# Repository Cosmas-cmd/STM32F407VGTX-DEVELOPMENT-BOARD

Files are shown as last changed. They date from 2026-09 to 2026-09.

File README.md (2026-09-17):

# Quick Preview
<p style="text-align:left;font-size:16px;color:white;">A custom STM32F407VGTx development board designed in KiCad 9.0, featuring the STM32F407 (LQFP100, Cortex-M4F @ 168 MHz) with an external crystal, USB Type-C power input, onboard microSD card slot, a user-programmable RGB LED, a "PWR ON" status LED, dedicated Wake-Up and Reset buttons, a BOOT0 force-boot jumper (JP1) for entering the system bootloader, an SWD/JTAG debug header for programming and debugging, and two 2×25 GPIO headers breaking out nearly the full MCU pinout along with 3V3/5V/GND rails for easy prototyping and shield/breadboard use.</p>
<p style="text-align:left;font-size:16px;color:white;text-decoration:underline">AN STM32F407VGTX BASED DEVELOPMENT BOARD</p>

<p style="margin-left:50px">
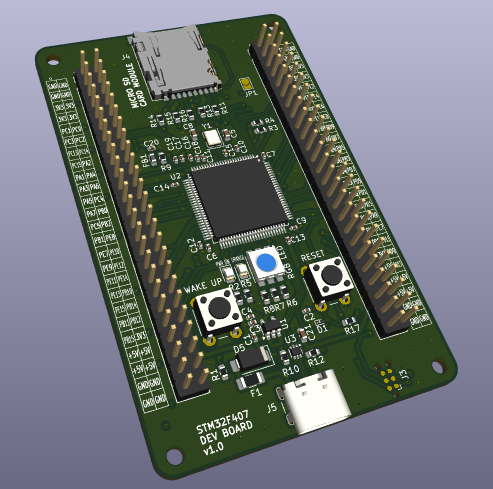
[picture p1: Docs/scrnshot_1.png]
  
</p>

<p style="text-align:left;font-size:16px;color:white">Frontside_1 view of the development board </p>

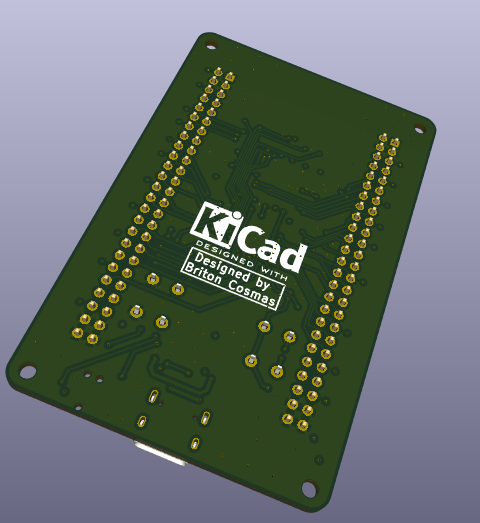
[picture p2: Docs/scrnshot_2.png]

</p>
<p style="text-align:left;font-size:16px;color:white">Bottomside view of the development board</p>

<p align="center">
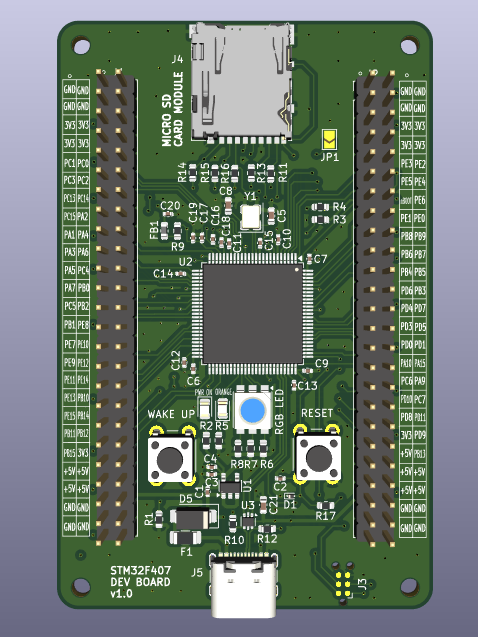
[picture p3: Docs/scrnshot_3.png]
  
</p>

<p style="text-align:left;font-size:16px;color:white">Frontside_2 view of the development board</p>

<p align="center">
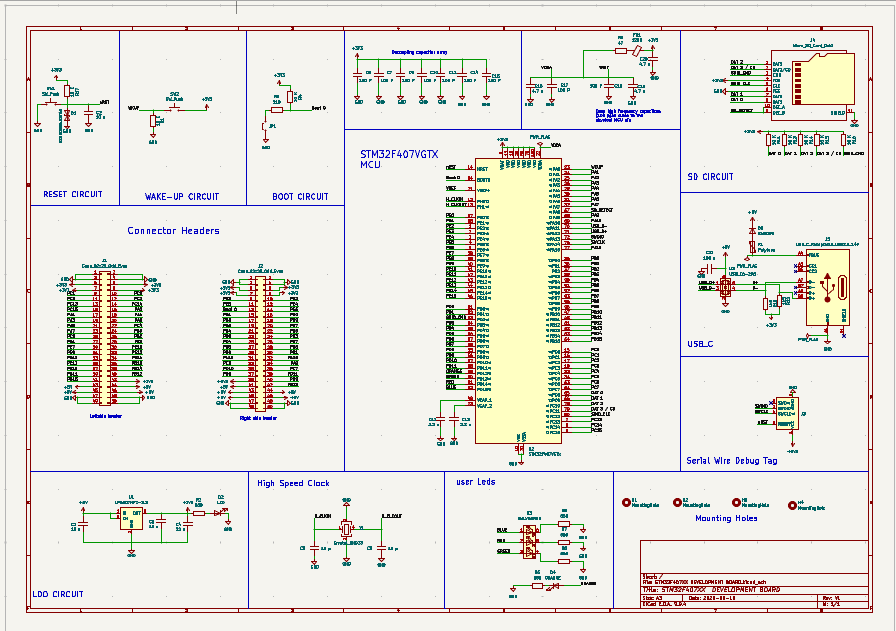
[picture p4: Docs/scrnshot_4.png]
  
</p>

<p style="text-align:left;font-size:16px;color:white">Schematic view of the development board circuit</p>
<p style="text-align:left;">**The schematic has also been provided as a pdf in this repository for clear viewing</p>

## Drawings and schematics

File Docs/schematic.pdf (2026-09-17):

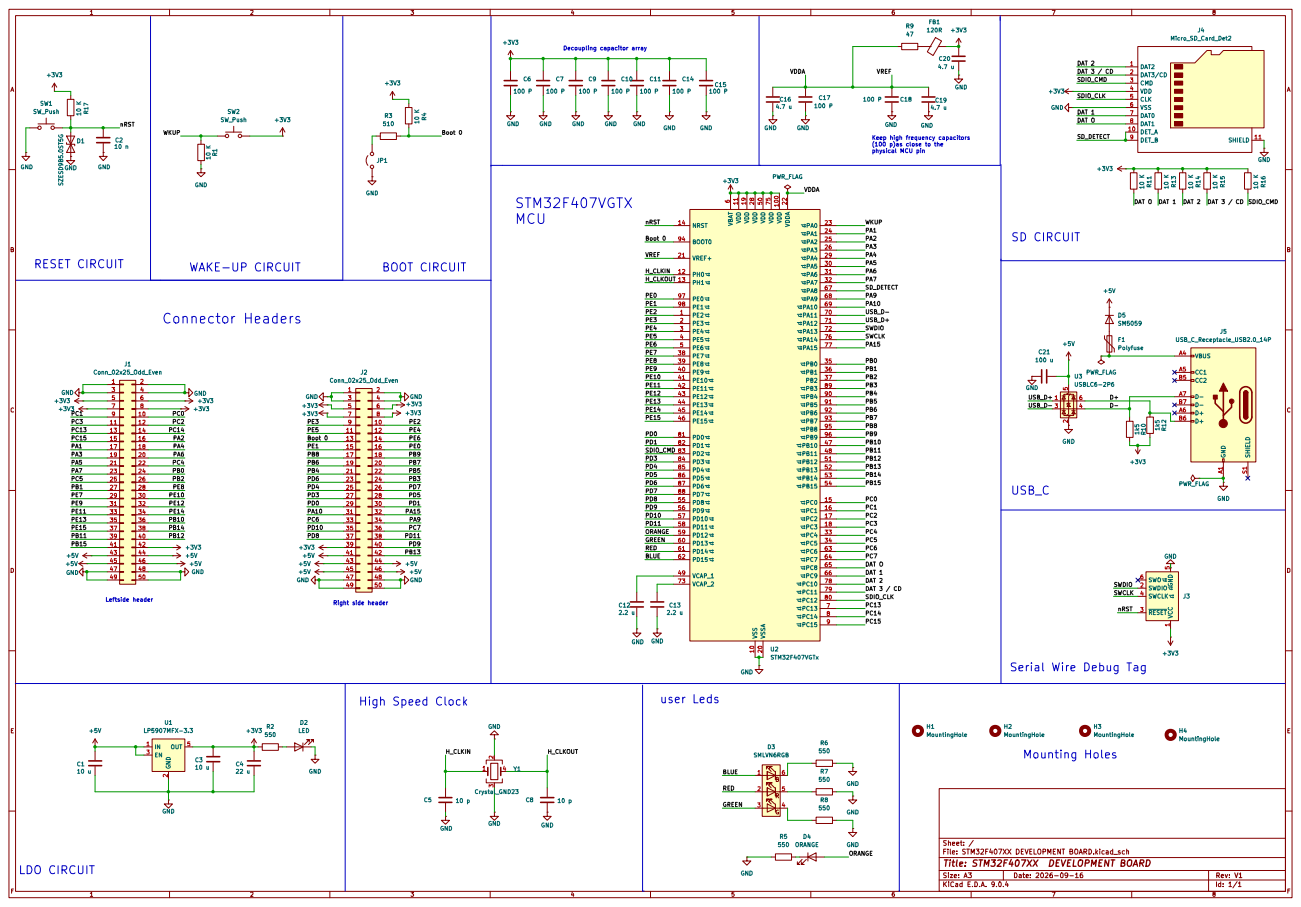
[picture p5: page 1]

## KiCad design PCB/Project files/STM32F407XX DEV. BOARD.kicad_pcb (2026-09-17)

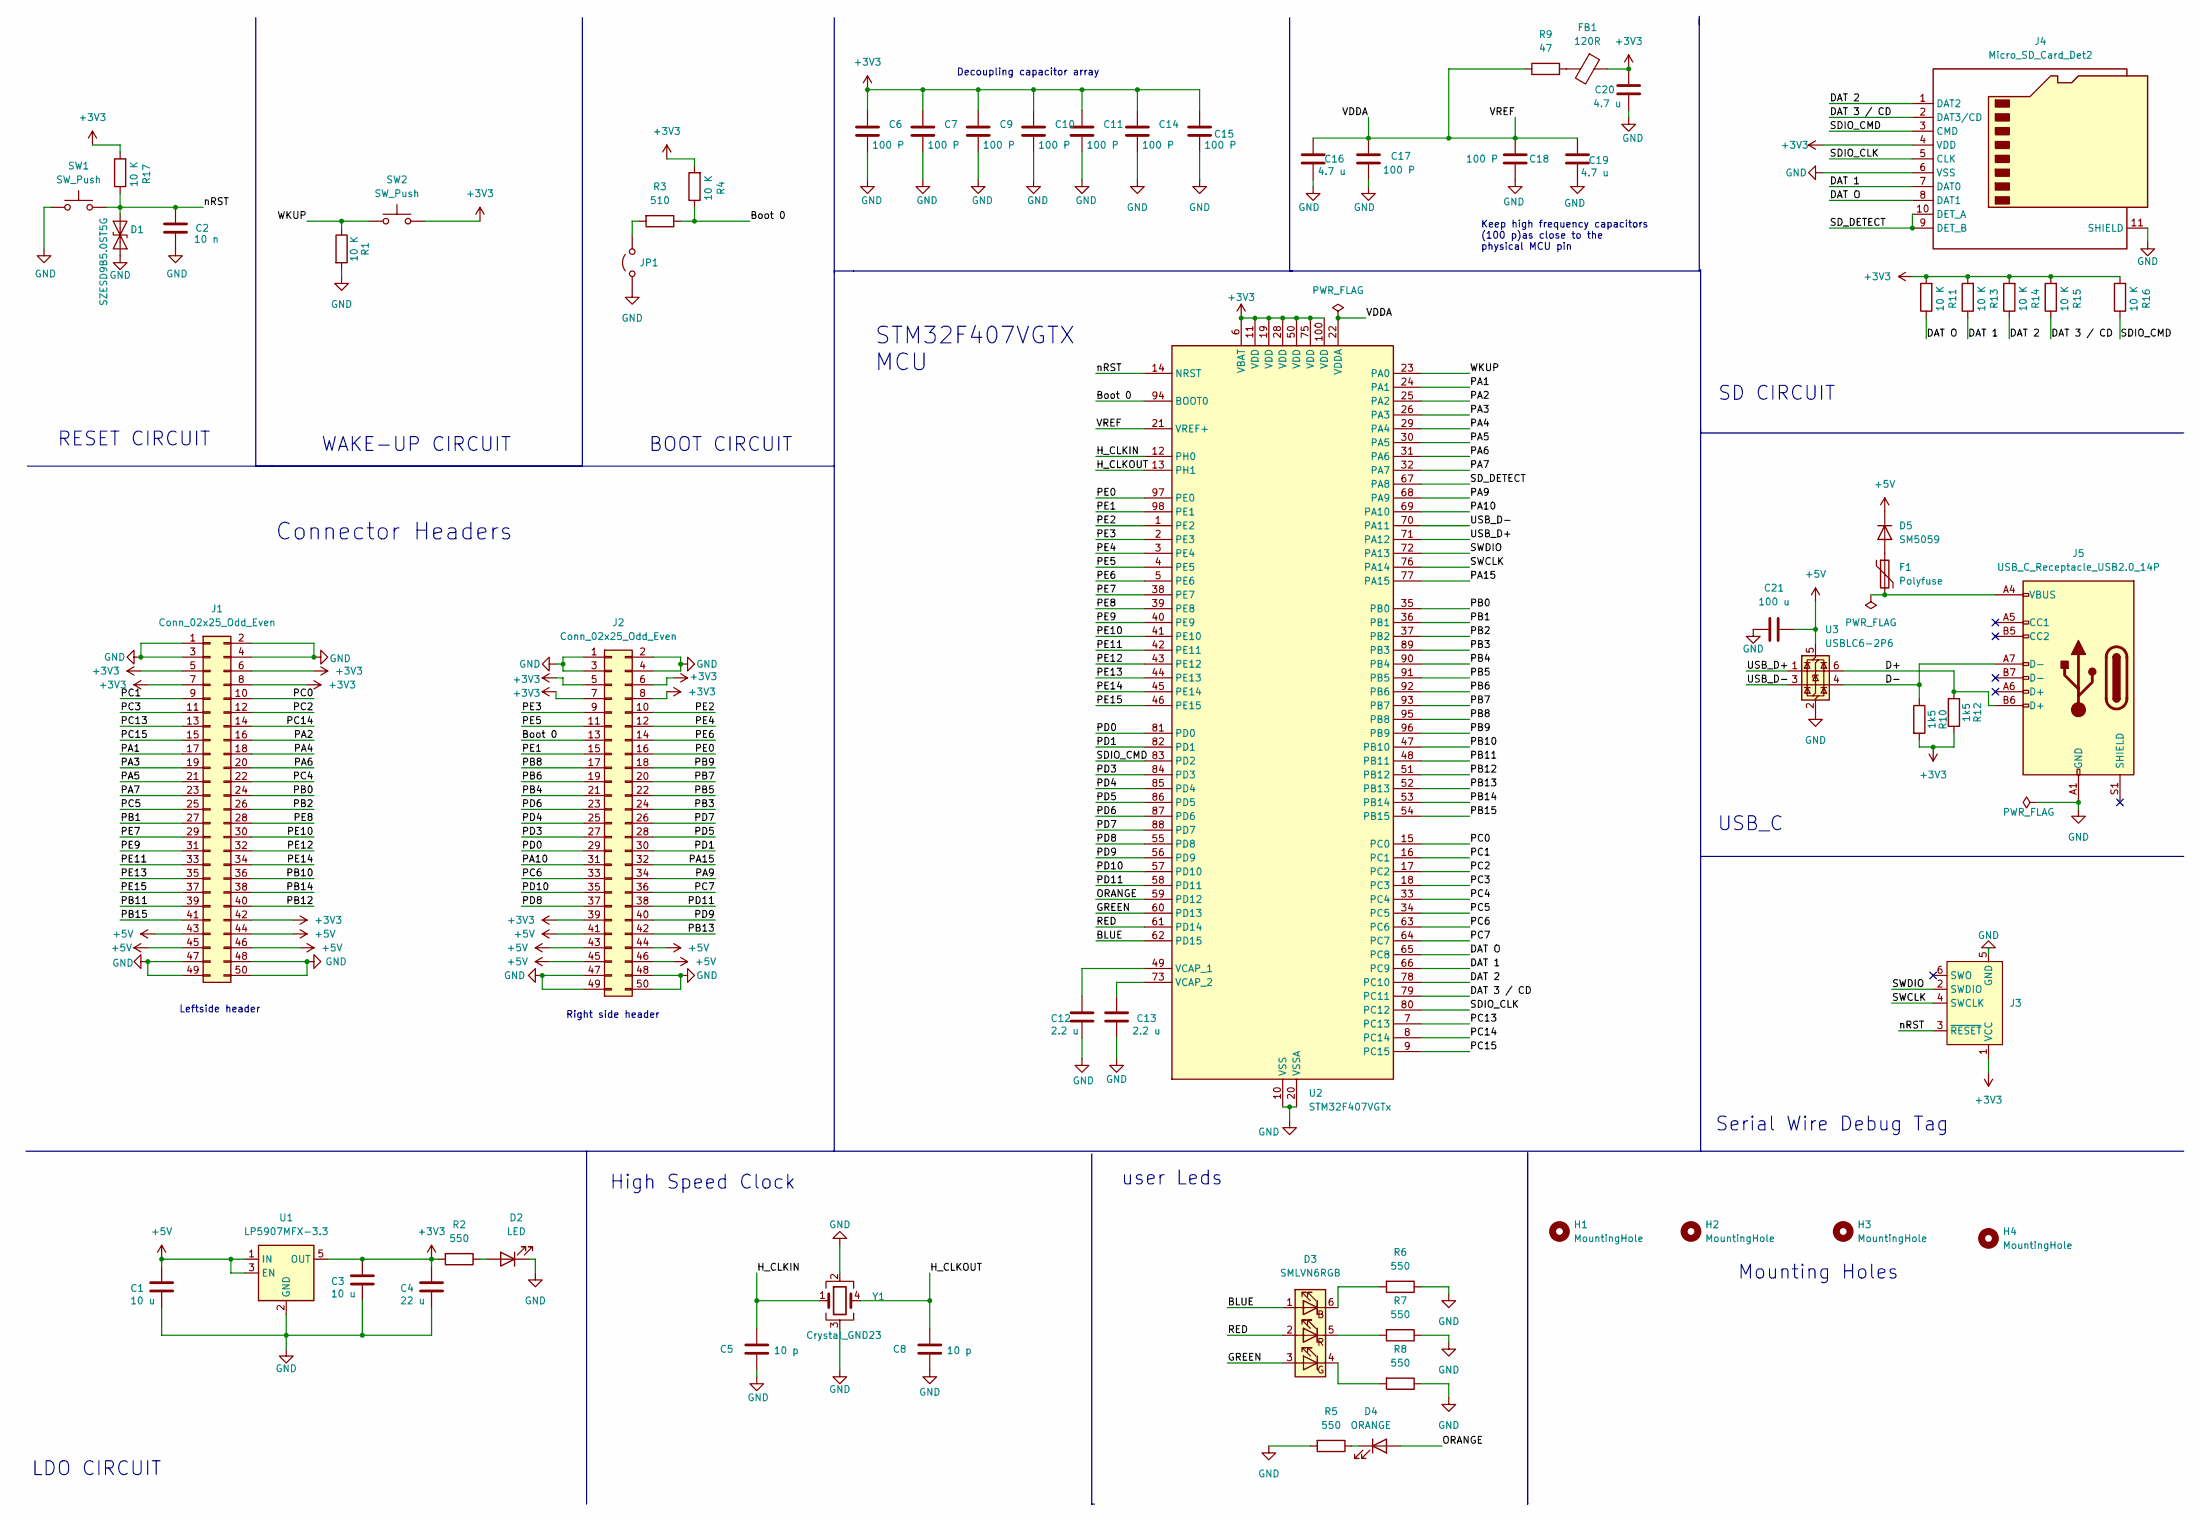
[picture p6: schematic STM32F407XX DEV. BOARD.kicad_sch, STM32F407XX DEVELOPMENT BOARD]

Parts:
C1, C3: 10 u; C_0402_1005Metric
C2: 10 n; C_0402_1005Metric
C4: 22 u; C_0402_1005Metric
C5, C8: 10 p; C_0603_1608Metric
C6, C7, C9, C10, C11, C14, C15, C17, C18: 100 P; C_0402_1005Metric
C12, C13: 2.2 u; C_0402_1005Metric
C16, C19, C20: 4.7 u; C_0402_1005Metric
C21: 100 u; C_0603_1608Metric
D1: SZESD9B5.0ST5G; D_SOD-923
D2: LED; LED_0805_2012Metric
D3: SMLVN6RGB; LED_RGB_5050-6
D4: ORANGE; LED_0805_2012Metric
D5: SM5059; D_SMA
F1: Polyfuse; Fuse_1206_3216Metric_Pad1.42x1.75mm_HandSolder
FB1: 120R; L_0603_1608Metric
H1, H2, H3, H4: MountingHole; MountingHole_2.5mm
J1, J2: Conn_02x25_Odd_Even; PinHeader_2x25_P2.54mm_Vertical
J3: Conn_ARM_SWD_TagConnect_TC2030-NL; Tag-Connect_TC2030-IDC-NL_2x03_P1.27mm_Vertical
J4: Micro_SD_Card_Det2; microSD_HC_Hirose_DM3AT-SF-PEJM5
J5: USB_C_Receptacle_USB2.0_14P; USB_C_Receptacle_GCT_USB4105-xx-A_16P_TopMnt_Horizontal
JP1: Jumper_2_Open; SolderJumper-2_P1.3mm_Open_TrianglePad1.0x1.5mm
R1, R4, R11, R13, R14, R15, R16, R17: 10 K; R_0603_1608Metric
R2, R5, R6, R7, R8: 550; R_0603_1608Metric
R3: 510; R_0603_1608Metric
R9: 47; R_0603_1608Metric
R10, R12: 1k5; R_0603_1608Metric
SW1, SW2: SW_Push; SW_PUSH_6mm
U1: LP5907MFX-3.3; SOT-23-5
U2: STM32F407VGTx; LQFP-100_14x14mm_P0.5mm
U3: USBLC6-2P6; SOT-666
Y1: Crystal_GND23; Crystal_SMD_3225-4Pin_3.2x2.5mm

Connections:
+3V3: C3.1, C4.1, C6.1, C7.1, C9.1, C10.1, C11.1, C14.1, C15.1, C20.1, FB1.1, J1.5, J1.6, J1.7, J1.8, J1.42, J2.5, J2.6, J2.7, J2.8, J2.39, J3.1 (VCC), J4.4 (VDD), R2.2, R4.2, R10.2, R11.2, R12.2, R13.2, R14.2, R15.2, R16.2, R17.2, SW2.2, U1.5 (OUT), U2.6 (VBAT), U2.11 (VDD), U2.19 (VDD), U2.28 (VDD), U2.50 (VDD), U2.75 (VDD), U2.100 (VDD)
+5V: C1.1, C21.2, D5.1 (K), J1.43, J1.44, J1.45, J1.46, J2.41, J2.43, J2.44, J2.45, J2.46, U1.1 (IN), U1.3 (EN), U3.5 (VBUS)
/BLUE: D3.1 (BA), U2.62 (PD15); also elsewhere on the board
/Boot 0: J2.13, R3.1, R4.1, U2.94 (BOOT0)
/D+: J5.B6 (D+), R12.1, U3.6 (I/O1)
/D-: J5.A7 (D-), R10.1, U3.4 (I/O2)
/DAT 1: J4.7 (DAT0), R13.1, U2.66 (PC9)
/DAT 2: J4.1 (DAT2), R14.1, U2.78 (PC10)
/DAT 3 / CD: J4.2 (DAT3/CD), R15.1, U2.79 (PC11)
/DAT O: J4.8 (DAT1), R11.1, U2.65 (PC8)
/GREEN: D3.3 (GA), U2.60 (PD13); also elsewhere on the board
/H_CLKIN: C5.1, U2.12 (PH0), Y1.1
/H_CLKOUT: C8.1, U2.13 (PH1), Y1.4
/ORANGE: D4.2 (A), U2.59 (PD12)
/PA1: J1.17, U2.24 (PA1)
/PA2: J1.16, U2.25 (PA2)
/PA3: J1.19, U2.26 (PA3)
/PA4: J1.18, U2.29 (PA4)
/PA5: J1.21, U2.30 (PA5)
/PA6: J1.20, U2.31 (PA6)
/PA7: J1.23, U2.32 (PA7)
/PA9: J2.34, U2.68 (PA9)
/PA10: J2.31, U2.69 (PA10)
/PA15: J2.32, U2.77 (PA15)
/PB0: J1.24, U2.35 (PB0)
/PB1: J1.27, U2.36 (PB1)
/PB2: J1.26, U2.37 (PB2)
/PB3: J2.24, U2.89 (PB3)
/PB4: J2.21, U2.90 (PB4)
/PB5: J2.22, U2.91 (PB5)
/PB6: J2.19, U2.92 (PB6)
/PB7: J2.20, U2.93 (PB7)
/PB8: J2.17, U2.95 (PB8)
/PB9: J2.18, U2.96 (PB9)
/PB10: J1.36, U2.47 (PB10)
/PB11: J1.39, U2.48 (PB11)
/PB12: J1.40, U2.51 (PB12)
/PB13: J2.42, U2.52 (PB13)
/PB14: J1.38, U2.53 (PB14)
/PB15: J1.41, U2.54 (PB15)
/PC0: J1.10, U2.15 (PC0)
/PC1: J1.9, U2.16 (PC1)
/PC2: J1.12, U2.17 (PC2)
/PC3: J1.11, U2.18 (PC3)
/PC4: J1.22, U2.33 (PC4)
/PC5: J1.25, U2.34 (PC5)
/PC6: J2.33, U2.63 (PC6)
/PC7: J2.36, U2.64 (PC7)
/PC13: J1.13, U2.7 (PC13)
/PC14: J1.14, U2.8 (PC14)
/PC15: J1.15, U2.9 (PC15)
/PD0: J2.29, U2.81 (PD0)
/PD1: J2.30, U2.82 (PD1)
/PD3: J2.27, U2.84 (PD3)
/PD4: J2.25, U2.85 (PD4)
/PD5: J2.28, U2.86 (PD5)
/PD6: J2.23, U2.87 (PD6)
/PD7: J2.26, U2.88 (PD7)
/PD8: J2.37, U2.55 (PD8)
/PD9: J2.40, U2.56 (PD9)
/PD10: J2.35, U2.57 (PD10)
/PD11: J2.38, U2.58 (PD11)
/PE0: J2.16, U2.97 (PE0)
/PE1: J2.15, U2.98 (PE1)
/PE2: J2.10, U2.1 (PE2)
/PE3: J2.9, U2.2 (PE3)
/PE4: J2.12, U2.3 (PE4)
/PE5: J2.11, U2.4 (PE5)
/PE6: J2.14, U2.5 (PE6)
/PE7: J1.29, U2.38 (PE7)
/PE8: J1.28, U2.39 (PE8)
/PE9: J1.31, U2.40 (PE9)
/PE10: J1.30, U2.41 (PE10)
/PE11: J1.33, U2.42 (PE11)
/PE12: J1.32, U2.43 (PE12)
/PE13: J1.35, U2.44 (PE13)
/PE14: J1.34, U2.45 (PE14)
/PE15: J1.37, U2.46 (PE15)
/RED: D3.2 (RA), U2.61 (PD14); also elsewhere on the board
/SDIO_CLK: J4.5 (CLK), U2.80 (PC12)
/SDIO_CMD: J4.3 (CMD), R16.1, U2.83 (PD2)
/SD_DETECT: J4.9 (DET_B), J4.10 (DET_A), U2.67 (PA8)
/SWCLK: J3.4 (SWCLK), U2.76 (PA14)
/SWDIO: J3.2 (SWDIO), U2.72 (PA13)
/USB_D+: U2.71 (PA12), U3.1 (I/O1)
/USB_D-: U2.70 (PA11), U3.3 (I/O2)
/VDDA: C16.1, C17.1, C18.1, C19.1, R9.1, U2.21 (VREF+), U2.22 (VDDA)
/WKUP: R1.1, SW2.1, U2.23 (PA0)
/nRST: C2.1, D1.2 (A2), J3.3 (~RESET), R17.1, SW1.2, U2.14 (NRST)
GND: C1.2, C2.2, C3.2, C4.2, C5.2, C6.2, C7.2, C8.2, C9.2, C10.2, C11.2, C12.2, C13.2, C14.2, C15.2, C16.2, C17.2, C18.2, C19.2, C20.2, C21.1, D1.1 (A1), D2.1 (K), J1.1, J1.2, J1.3, J1.4, J1.47, J1.48, J1.49, J1.50, J2.1, J2.2, J2.3, J2.4, J2.47, J2.48, J2.49, J2.50, J3.5 (GND), J4.6 (VSS), J4.11 (SHIELD), J5.A1 (GND), J5.A12 (GND), J5.B1 (GND), J5.B12 (GND), JP1.1 (A), R1.2, R5.2, R6.1, R7.1, R8.1, SW1.1, U1.2 (GND), U2.10 (VSS), U2.20 (VSSA), U2.27 (VSS), U2.74 (VSS), U2.99 (VSS), U3.2 (GND), Y1.2, Y1.3
unnamed: D2.2 (A), R2.1
unnamed 91: D3.6 (BK), R6.2; also elsewhere on the board
unnamed 92: D3.4 (GK), R8.2; also elsewhere on the board
unnamed 93: D3.5 (RK), R7.2; also elsewhere on the board
unnamed: D4.1 (K), R5.1
unnamed: D5.2 (A), F1.1
unnamed: F1.2, J5.A4 (VBUS), J5.A9 (VBUS), J5.B4 (VBUS), J5.B9 (VBUS)
unnamed: FB1.2, R9.2
unnamed: JP1.2 (B), R3.2
unnamed: C12.1, U2.49 (VCAP_1)
unnamed: C13.1, U2.73 (VCAP_2)

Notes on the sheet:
High Speed Clock
USB_C
BOOT CIRCUIT
Leftside header
Mounting Holes
Decoupling capacitor array
Serial Wire Debug Tag
SD CIRCUIT
LDO CIRCUIT
WAKE-UP CIRCUIT
Keep high frequency capacitors (100 p)as close to the physical MCU pin
RESET CIRCUIT
Right side header
user Leds
STM32F407VGTX MCU
Connector Headers

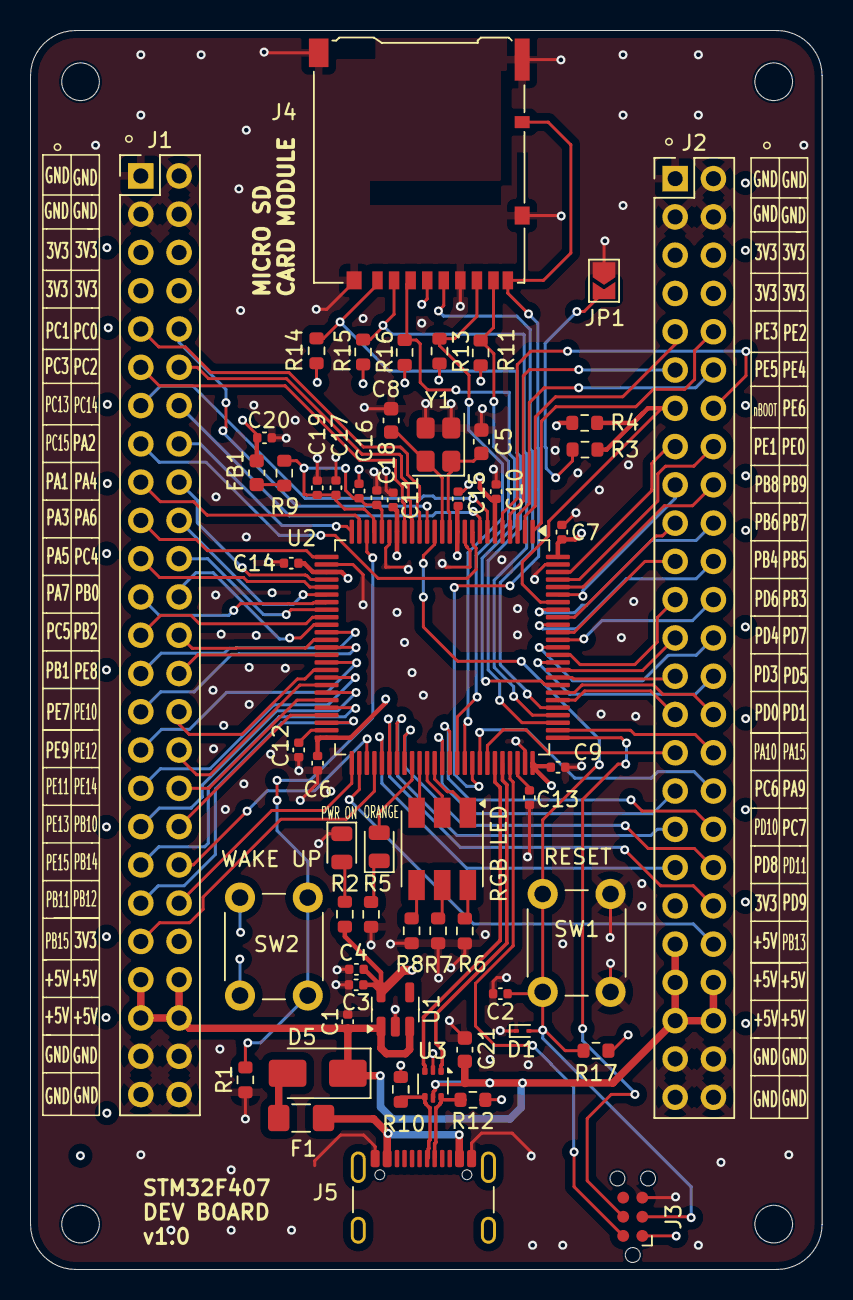
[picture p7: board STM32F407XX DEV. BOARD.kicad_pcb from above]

Board: 4 copper layers, 52.5 x 82.2 mm, 61 parts (0 on the bottom side), 101 nets.

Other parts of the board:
RGB LED: SMLVN6RGB; LED_RGB_5050-6

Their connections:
/BLUE: RGB LED.1 (BA); also elsewhere on the board
/GREEN: RGB LED.3 (GA); also elsewhere on the board
/RED: RGB LED.2 (RA); also elsewhere on the board
unnamed 91: RGB LED.6 (BK); also elsewhere on the board
unnamed 92: RGB LED.4 (GK); also elsewhere on the board
unnamed 93: RGB LED.5 (RK); also elsewhere on the board

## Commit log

2026-09-17 :star: Initial commit
    [STM32F407XX DEV. BOARD.kicad_pcb, STM32F407XX DEV. BOARD.kicad_sch]
2026-09-17 Add README with board details and images
    Added detailed description and images of the STM32F407VGTx development board.
